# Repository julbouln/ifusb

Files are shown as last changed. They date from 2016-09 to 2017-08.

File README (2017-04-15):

ifusb is a simple toolkit to access GPIO/UART/SPI/I2C from USB host through microcontroller.
It was initialy attended for use with eink controller project, but can be used as a tool for any project, like a Bus Pirate board or a FT2232 chip.

Firmware use libopencm3 and has been tested with STM32F042 microcontroller.
PR 663 is needed for I2C on STM32F0 https://github.com/libopencm3/libopencm3/pull/663
$ git fetch origin pull/663/head:pr-663
$ git checkout pr-663

Do not forget to edit OPENCM3_DIR in firmware/Makefine to your libopencm3 path.

Host library use libusb 1.0.

Finally, a reference design is available in hardware/ directory.

ifusb user access udev rules:
SUBSYSTEM=="usb", ATTR{idVendor}=="f055", ATTR{idProduct}=="cafe", MODE="0666"

TODO
- UART RX + MIN

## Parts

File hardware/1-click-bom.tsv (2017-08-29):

References | Qty | Description | Manufacturer | MPN | Manufacturer | MPN | Manufacturer | MPN | Digikey | Mouser | RS | Newark | Farnell
JP1, JP2 | 2 | PIN HEADER 1X10 | Molex | 22-28-4103 | Molex | 22-28-4106 | Harwin | M20-9991045 | 952-1842-ND | 53822284103 | 7457071 | 56H2018 | 1022261
PWR | 1 | LED 0603 RED | Dialight | 597-5004-407F | Dialight | 597-5112-402F | Avago | HSMC-C190 | 350-2890-ND | 78VLMW1300GS08 | 7008039 | 30K5003 | 1867024
CN1 | 1 | Molex USB mini B receptacle | Molex | 565790519 |  |  |  |  | WM17121-ND | 538565790519 | 5152011 | 20M7443 | 1125347
C2, C4 | 2 | 100nF 0603 | Yageo | CC0603KRX7R9BB104 | Murata | GRM188R71H104KA93D |  |  | 490-1519-6-ND | 603CC603KRX7R9BB104 | 7235676 | 68R4788 | 8820023
R1 | 1 | 10k 0603 | Yageo | RC0603FR-0710KL | Panasonic | ERJ-3EKF1002V | Vishay | CRCW060310K0FKEA | P10.0KHDKR-ND | 71CRCW060310KE3 | 8206742 | 64R5309 | 2303192
R2 | 1 | 1k 0603 | Yageo | RC0603FR-071KL | Panasonic | ERJ-3EKF1001V | Vishay | CRCW06031K00FKEA | 311-1.00KHRDKR-ND | 603RC0603FR071KL | 6789875 | 52K8015 | 2303145
C1, C3 | 2 | 1uF 0603 | Yageo | CC0603KRX7R8BB105 | Murata | GRM188R71E105KA12D |  |  | 311-1802-6-ND | 603CC603KRX7R8BB105 | 7235632 | 91R0949 | 1735540
R3, R4 | 2 | 22 Ohm 0603 | Yageo | RC0603FR-0722RL | Panasonic | ERJ-3EKF22R0V | Vishay | CRCW060322R0FKEA | P22.0HCT-ND | 667ERJ3EKF22R0V | 8206809 | 64R5327 | 2302996
U1 | 1 | Low Quiescent Current LDO | Microchip | MCP1700T-3302E/TT |  |  |  |  | MCP1700T3302ETTDKR-ND | 579MCP1700T3302E/TT | 8877429 | 88H9817 | 1296592
U2 | 1 | STM32F042Fx TSSOP20 | STMicroelectronics | STM32F042F4P6 |  |  |  |  | 497-17343-ND | 511STM32F042F4P6 | 8607491P | 42Y1014 | 2469548

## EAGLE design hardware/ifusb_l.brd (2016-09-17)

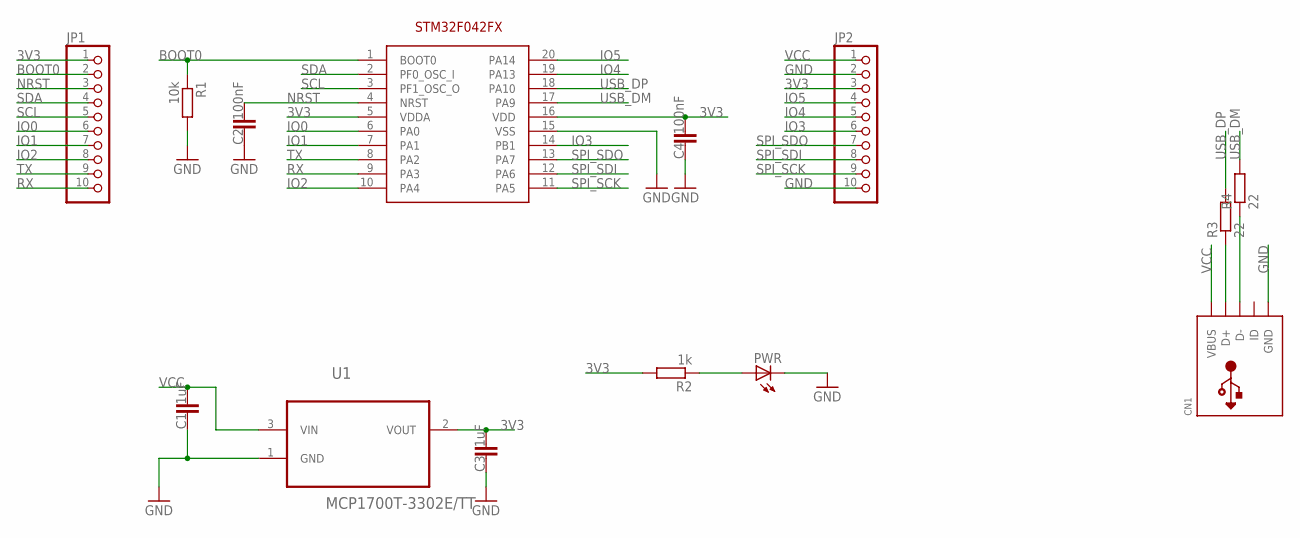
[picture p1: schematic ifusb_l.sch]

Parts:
C1, C3: 1uF; C0603K
C2, C4: 100nF; C0603K
CN1: USBMOLEX; USB-MINIB-THM-MOLEX
JP1, JP2: HEADER-1X10ROUND; 1X10_ROUND
PWR: LEDCHIP-LED0603; CHIP-LED0603
R1: 10k; R0603
R2: 1k; R0603
R3, R4: 22; R0603
U1: MCP1700T-3302E/TT; SOT95P237X112-3N
U2: STM32F042FX; TSSOP20

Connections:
3V3: C3.2, C4.2, JP1.1, JP2.3, R2.2, U1.2 (VOUT), U2.5 (VDDA), U2.16 (VDD)
BOOT0: JP1.2, R1.1, U2.1 (BOOT0)
GND: C1.1, C2.1, C3.1, C4.1, CN1.GND, JP2.2, JP2.10, PWR.C, R1.2, U1.1 (GND), U2.15 (VSS)
IO0: JP1.6, U2.6 (PA0)
IO1: JP1.7, U2.7 (PA1)
IO2: JP1.8, U2.10 (PA4)
IO3: JP2.6, U2.14 (PB1)
IO4: JP2.5, U2.19 (PA13)
IO5: JP2.4, U2.20 (PA14)
unnamed: CN1.D+, R3.1
unnamed: CN1.D-, R4.1
unnamed: PWR.A, R2.1
NRST: C2.2, JP1.3, U2.4 (NRST)
RX: JP1.10, U2.9 (PA3)
SCL: JP1.5, U2.3 (PF1_OSC_O)
SDA: JP1.4, U2.2 (PF0_OSC_I)
SPI_SCK: JP2.9, U2.11 (PA5)
SPI_SDI: JP2.8, U2.12 (PA6)
SPI_SDO: JP2.7, U2.13 (PA7)
TX: JP1.9, U2.8 (PA2)
USB_DM: R4.2, U2.17 (PA9)
USB_DP: R3.2, U2.18 (PA10)
VCC: C1.2, CN1.VBUS, JP2.1, U1.3 (VIN)

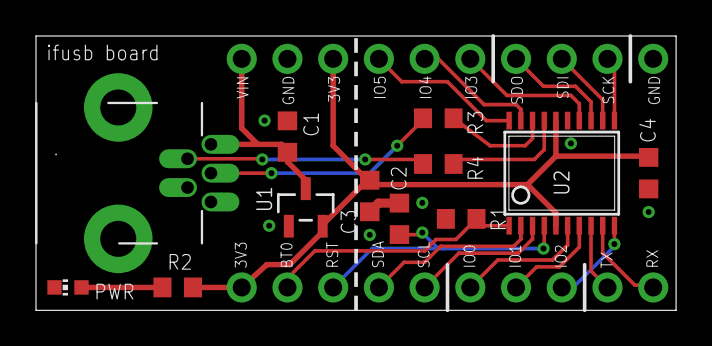
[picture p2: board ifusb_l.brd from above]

Board: 2 copper layers, 35.6 x 15.2 mm, 14 parts (0 on the bottom side), 23 nets.

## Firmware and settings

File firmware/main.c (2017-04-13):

/*
 * This file is part of the libopencm3 project.
 *
 * Copyright (C) 2009 Uwe Hermann <uwe@hermann-uwe.de>
 * Copyright (C) 2011 Stephen Caudle <scaudle@doceme.com>
 * Copyright (C) 2012 Karl Palsson <karlp@tweak.net.au>
 *
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
 * You should have received a copy of the GNU Lesser General Public License
 * along with this library.  If not, see <http://www.gnu.org/licenses/>.
 */


#include <stdio.h>
#include <stdlib.h>
#include <ctype.h>

#include <libopencm3/stm32/rcc.h>
#include <libopencm3/stm32/gpio.h>
#include <libopencm3/cm3/nvic.h>
#include <libopencm3/cm3/systick.h>
#include <libopencm3/stm32/usart.h>
#include <libopencm3/stm32/spi.h>
#include <libopencm3/stm32/dma.h>

#include <libopencm3/stm32/crs.h>
#include <libopencm3/stm32/syscfg.h>

#include <libopencm3/cm3/scb.h>
#include <libopencm3/stm32/pwr.h>

#include "usb.h"
#include "board.h"
#include "ifusb.h"

volatile uint32_t system_millis;

/* Called when systick fires */
void sys_tick_handler(void)
{
	system_millis++;
}

/* sleep for delay milliseconds */
static void delay(uint32_t delay)
{
	uint32_t wake = system_millis + delay;
	while (wake > system_millis);
}

/* Set up a timer to create 1mS ticks. */
static void systick_setup(void)
{
	/* clock rate / 1000 to get 1mS interrupt rate */
	systick_set_reload(48000);
	systick_set_clocksource(STK_CSR_CLKSOURCE_AHB);
	systick_counter_enable();
	/* this done last */
	systick_interrupt_enable();
}

static void gpio_setup(void)
{
	int pin;
// set all gpio to input
	for(pin=0;pin<6;pin++) {
		gpio_mode_setup(gpio_map[pin][0], GPIO_MODE_INPUT, GPIO_PUPD_NONE, gpio_map[pin][1]);
	}

//	gpio_mode_setup(LED_PORT, GPIO_MODE_OUTPUT, GPIO_PUPD_NONE, LED_PIN);
}

#define __WFI() __asm__("wfi")
#define __WFE() __asm__("wfe")

void sleep_mode(int deepSleepFlag)
{
	// Clear PDDS and LPDS bits
	PWR_CR &= PWR_CR_LPDS | PWR_CR_PDDS | PWR_CR_CWUF;

	// Set PDDS and LPDS bits for standby mode, and set Clear WUF flag (required per datasheet):
	PWR_CR |= PWR_CR_CWUF;
	PWR_CR |= PWR_CR_PDDS;
	// Enable wakeup pin bit.
	PWR_CR |=  PWR_CSR_EWUP;

	// Low-power deepsleep bit.
	// PWR_CR |= PWR_CR_LPDS;

	// System Control Register Bits. See...
	// http://infocenter.arm.com/help/index.jsp?topic=/com.arm.doc.dui0497a/Cihhjgdh.html
	if (deepSleepFlag)
	{	// Experimental
		// Set Power down deepsleep bit.
		PWR_CR |= PWR_CR_PDDS;
		// Unset Low-power deepsleep.
		PWR_CR &= ~PWR_CR_LPDS;
		// Set sleepdeep in the system control register - if set, we deepsleep and coldstart from RTC or pin interrupts.
//    SCB_SCR |= SCB_SCR_SLEEPDEEP;
	} else {
		//  Unset Power down deepsleep bit.
		PWR_CR &= ~PWR_CR_PDDS;
		// set Low-power deepsleep.
		PWR_CR |= PWR_CR_LPDS;
		/*
		 * PWR_CR_PDDS
		    Power down deepsleep.
		   PWR_CR_LPDS
		    Low-power deepsleep.
		 */
		// Unset sleepdeep in the system control register - if not set then we only sleep and can wake from RTC or pin interrupts.
//    SCB_SCR |= SCB_SCR_SLEEPDEEP;
		// Low-power deepsleep bit.
	}

	// Set end Event on Pending bit: - enabled events and all interrupts, including disabled interrupts, can wakeup the processor.
	SCB_SCR |= SCB_SCR_SEVEONPEND;


	// Set SLEEPONEXIT -Indicates sleep-on-exit when returning from Handler mode to Thread mode -
	// if enabled, we will effectively sleep from the end of  one interrupt till the start of the next.
	SCB_SCR |= SCB_SCR_SLEEPONEXIT;


//	SCB_SCR &= ~SCB_SCR_SLEEPDEEP;

	// Now go into stop mode, wake up on interrupt
	// asm("    wfi");
//	__WFI();

}

void pow_init() {
	SCB_SCR &= ~SCB_SCR_SLEEPDEEP;
	SCB_SCR |= SCB_SCR_SLEEPONEXIT;
}

void rcc_init() {
#ifdef IFUSB_BOARD
	// crystal-less ?
	rcc_clock_setup_in_hsi48_out_48mhz();
	rcc_periph_clock_enable(RCC_SYSCFG_COMP);
	SYSCFG_CFGR1 |= SYSCFG_CFGR1_PA11_PA12_RMP;
	crs_autotrim_usb_enable();
	rcc_set_usbclk_source(RCC_HSI48);
#else
	rcc_clock_setup_in_hsi_out_48mhz();
#endif

	rcc_periph_clock_enable(RCC_GPIOA);
	rcc_periph_clock_enable(RCC_GPIOB);
	rcc_periph_clock_enable(RCC_GPIOF);

	rcc_periph_clock_enable(RCC_DMA);

	rcc_periph_clock_enable(RCC_USARTN);
	rcc_periph_clock_enable(RCC_SPI1);
	rcc_periph_clock_enable(RCC_I2C1);

}

void rcc_disable() {
	rcc_periph_clock_disable(RCC_GPIOA);
	rcc_periph_clock_disable(RCC_GPIOB);
	rcc_periph_clock_disable(RCC_GPIOF);

	rcc_periph_clock_disable(RCC_DMA);

	rcc_periph_clock_disable(RCC_USARTN);
	rcc_periph_clock_disable(RCC_SPI1);
	rcc_periph_clock_disable(RCC_I2C1);
}

void sys_init() {

	rcc_init();
	gpio_setup();
//	systick_setup();


	usart_setup();
	spi_setup();
	i2c_setup();

//	gpio_set(LED_PORT, LED_PIN);

//	sleep_mode(0);

	usb_setup();
	ifusb_init();
}

int main(void)
{
	sys_init();
//	delay(100);

#ifdef USB_USE_INT
	pow_init();
#endif

	while (1) {
#ifdef USB_USE_INT
		__WFI();

#else
		usb_poll();
#endif
	}

	return 0;
}

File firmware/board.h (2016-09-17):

#ifndef BOARD_H
#define BOARD_H

#define IFUSB_BOARD 1

#define LED_PORT GPIOB
#define LED_PIN GPIO3

#define USB_PORT GPIOA
#define USB_DM_PIN GPIO11
#define USB_DP_PIN GPIO12

// USART
#define USARTN USART2
#define USART_GPIO_AF GPIO_AF1
#define RCC_USARTN RCC_USART2
#define NVIC_USARTN_IRQ NVIC_USART2_IRQ
#define USARTN_TDR USART2_TDR
#define USART_PORT GPIOA
#define USART_TX_PIN GPIO2
#define USART_RX_PIN GPIO3

// DMA
#define USART_DMA_TX_CH DMA_CHANNEL4 // fixed mapping
#define USART_DMA_RX_CH DMA_CHANNEL5 // fixed mapping

#define SPI_DMA_RX_CH DMA_CHANNEL2 // fixed mapping
#define SPI_DMA_TX_CH DMA_CHANNEL3 // fixed mapping

static uint32_t gpio_map[6][2] = {
	{GPIOA,GPIO0},
	{GPIOA,GPIO1},
	{GPIOA,GPIO4},
#ifdef IFUSB_BOARD
	{GPIOB,GPIO1},
	{GPIOA,GPIO13},
	{GPIOA,GPIO14}
#else
	{GPIOB,GPIO0},
	{GPIOB,GPIO1},
	{GPIOA,GPIO8}
#endif
};

// other config
#define SPI_USE_DMA 1
#define USART_USE_DMA 1
#define USB_USE_INT 1

#endif

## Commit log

2017-04-15 add preliminary ruby binding
    [ifusb.c, ifusb_host.c]
2017-08-29 Make compatible with kitnic.it
    [1-click-bom.tsv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]

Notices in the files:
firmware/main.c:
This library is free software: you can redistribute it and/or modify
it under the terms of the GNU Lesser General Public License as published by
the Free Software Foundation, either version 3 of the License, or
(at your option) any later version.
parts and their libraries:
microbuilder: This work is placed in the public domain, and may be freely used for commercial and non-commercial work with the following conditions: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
